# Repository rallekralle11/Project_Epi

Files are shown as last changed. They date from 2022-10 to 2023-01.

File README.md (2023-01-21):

# Epi
# This thing is about to get launched on Crowd Supply!
Also take a look at the better 4-layered version: https://github.com/rallekralle11/Epi_4L

Named after the Epipactis genus or orchids. The flower of one appears on the board.

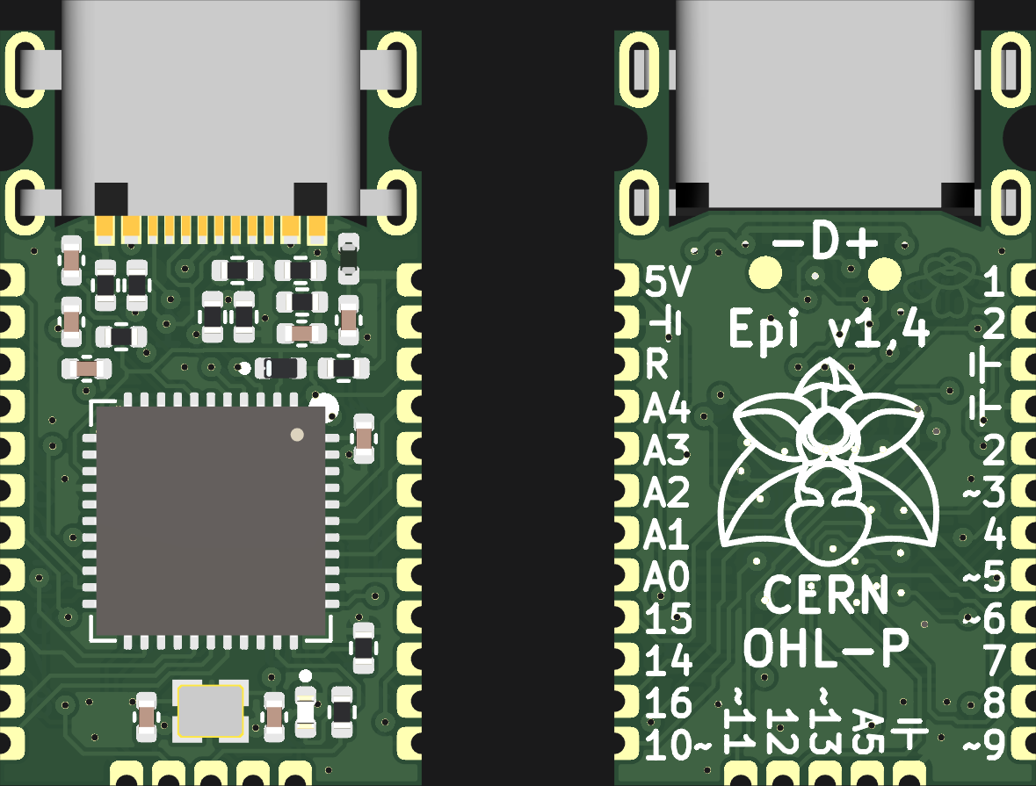
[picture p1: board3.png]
board


With such "amazing" features as:

Data line ESD protection taken from the official A. micro.

Crenellated pins.

No integrated voltage converter, only runs at 4,5-5,5v(down to 2,7 if you make it with an 8mhz crystal, or use the internal oscillator).

USB-C connector sunk into the board, and slighly portruding from the end for panel mounting.

1,27mm pin spacing.

Extra pins broken out.

Way too many hours routing for my sanity, and i doubt it's optimal(i am a beginner).

Holes where M2 bolts can be used to hold it in place.

No rx/tx/power LEDs. Only one on pin 13 for testing.

Includes some custom footprints with 3D models.

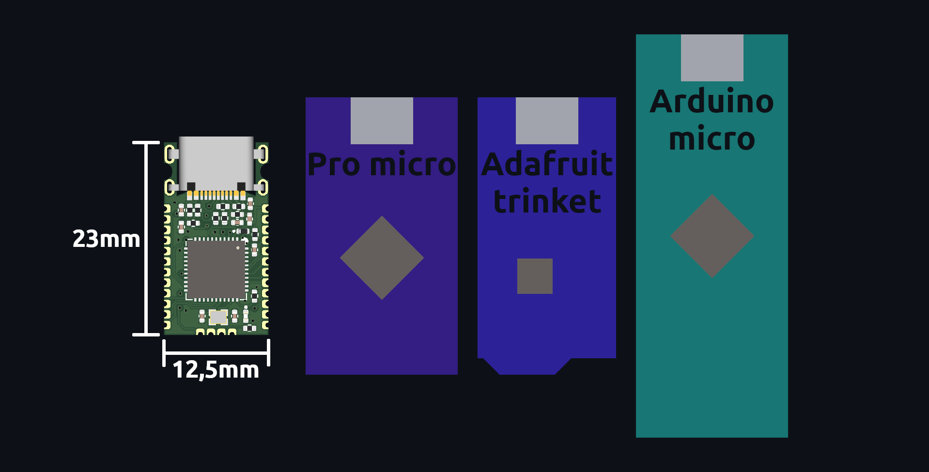
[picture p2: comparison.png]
comp

Size comparisons.

Licensed under CERN-OHL-P v2

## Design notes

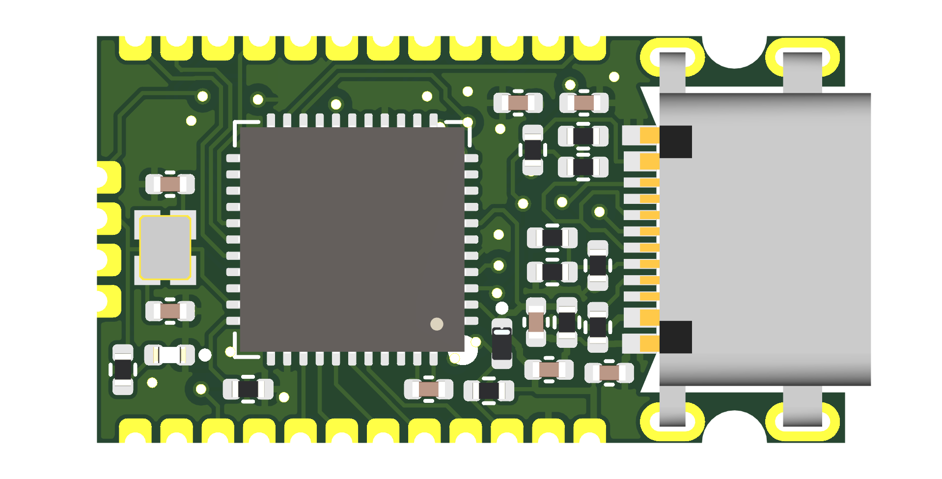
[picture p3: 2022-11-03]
diagram/pinout.png

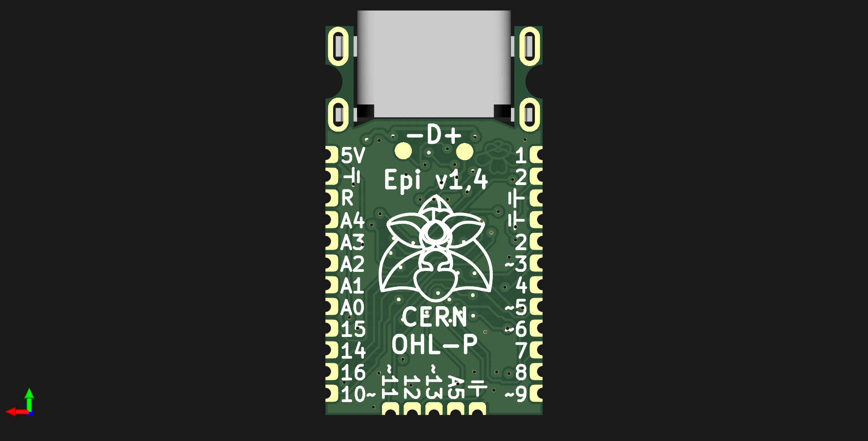
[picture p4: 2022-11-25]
B.png

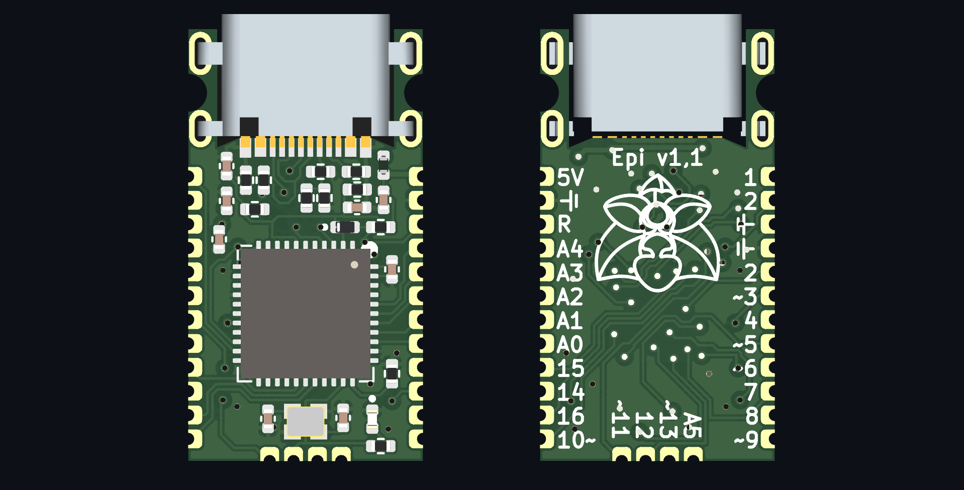
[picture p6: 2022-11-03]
gerbers/board2.png

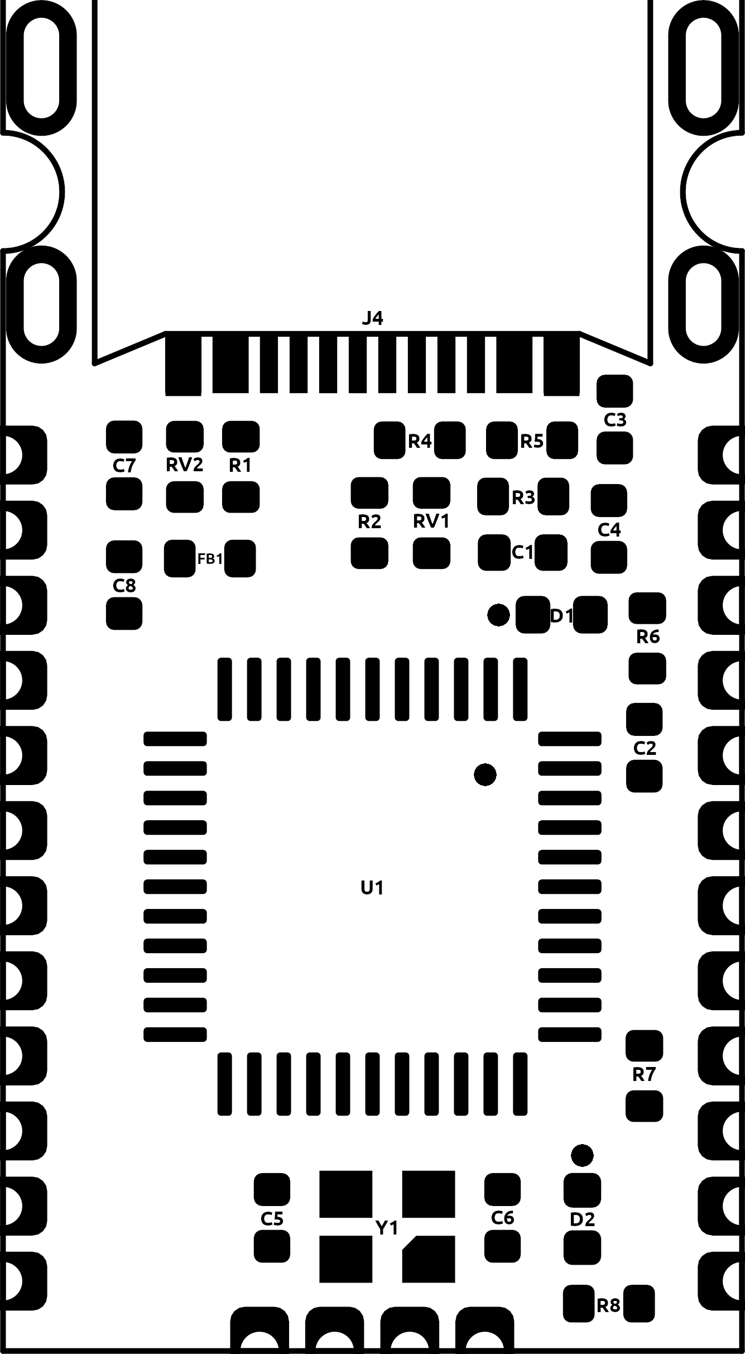
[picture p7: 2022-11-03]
diagram/layout.png

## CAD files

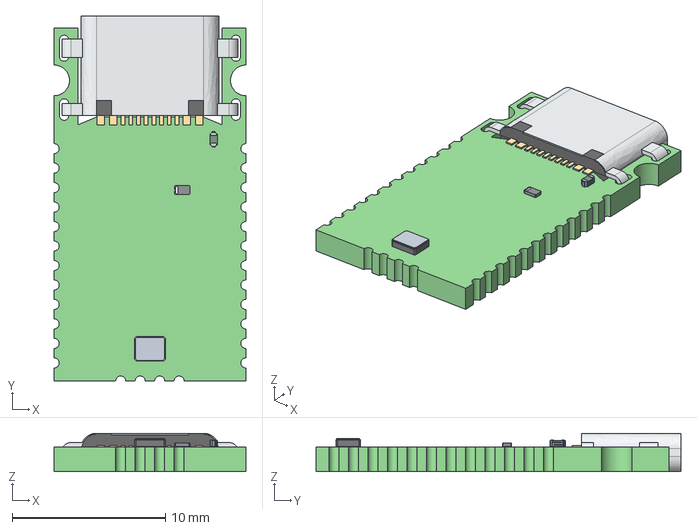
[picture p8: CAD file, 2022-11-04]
epi.step
12.5 x 23.8 x 2.50 mm
epi PCB

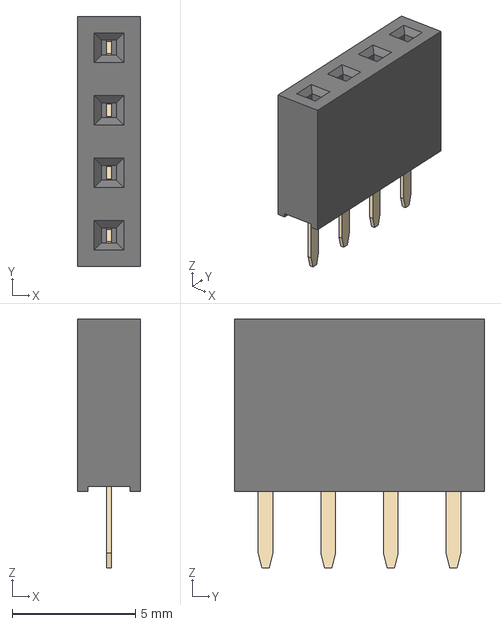
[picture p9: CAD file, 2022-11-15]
extra/PinSocket_1x04_P2.54mm_Vertical.step
2.54 x 10.2 x 10.1 mm

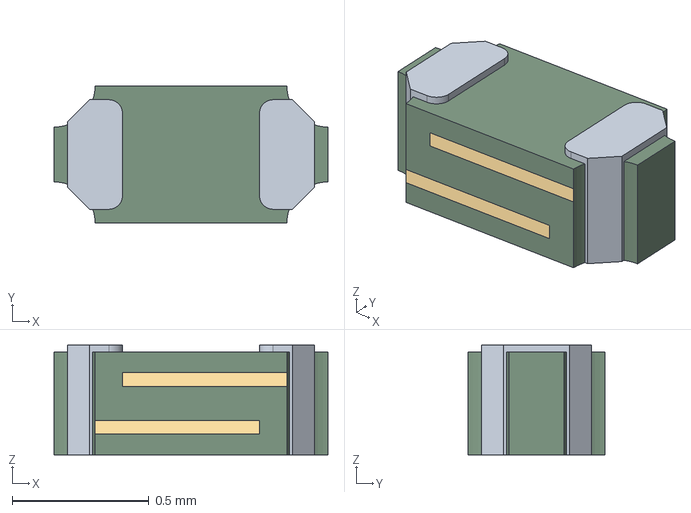
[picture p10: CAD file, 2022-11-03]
extra/1005_polyfuse.stp
1.00 x 0.5 x 0.4 mm

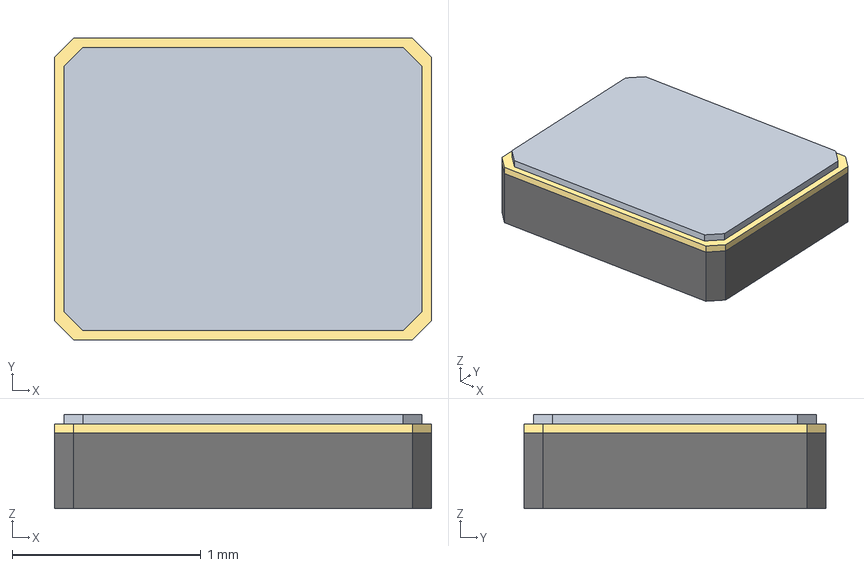
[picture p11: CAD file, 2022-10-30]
extra/crystal.stp
2.00 x 1.60 x 0.5 mm

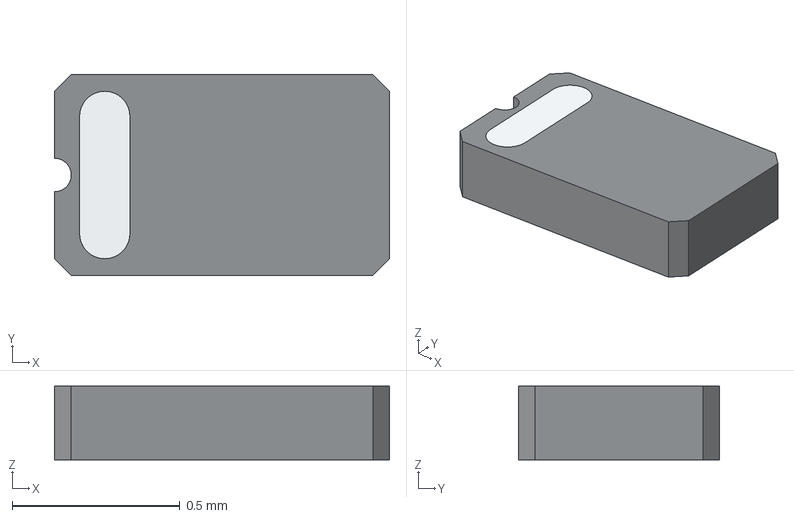
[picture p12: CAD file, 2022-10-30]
extra/diode.stp
1.00 x 0.6 x 0.22 mm

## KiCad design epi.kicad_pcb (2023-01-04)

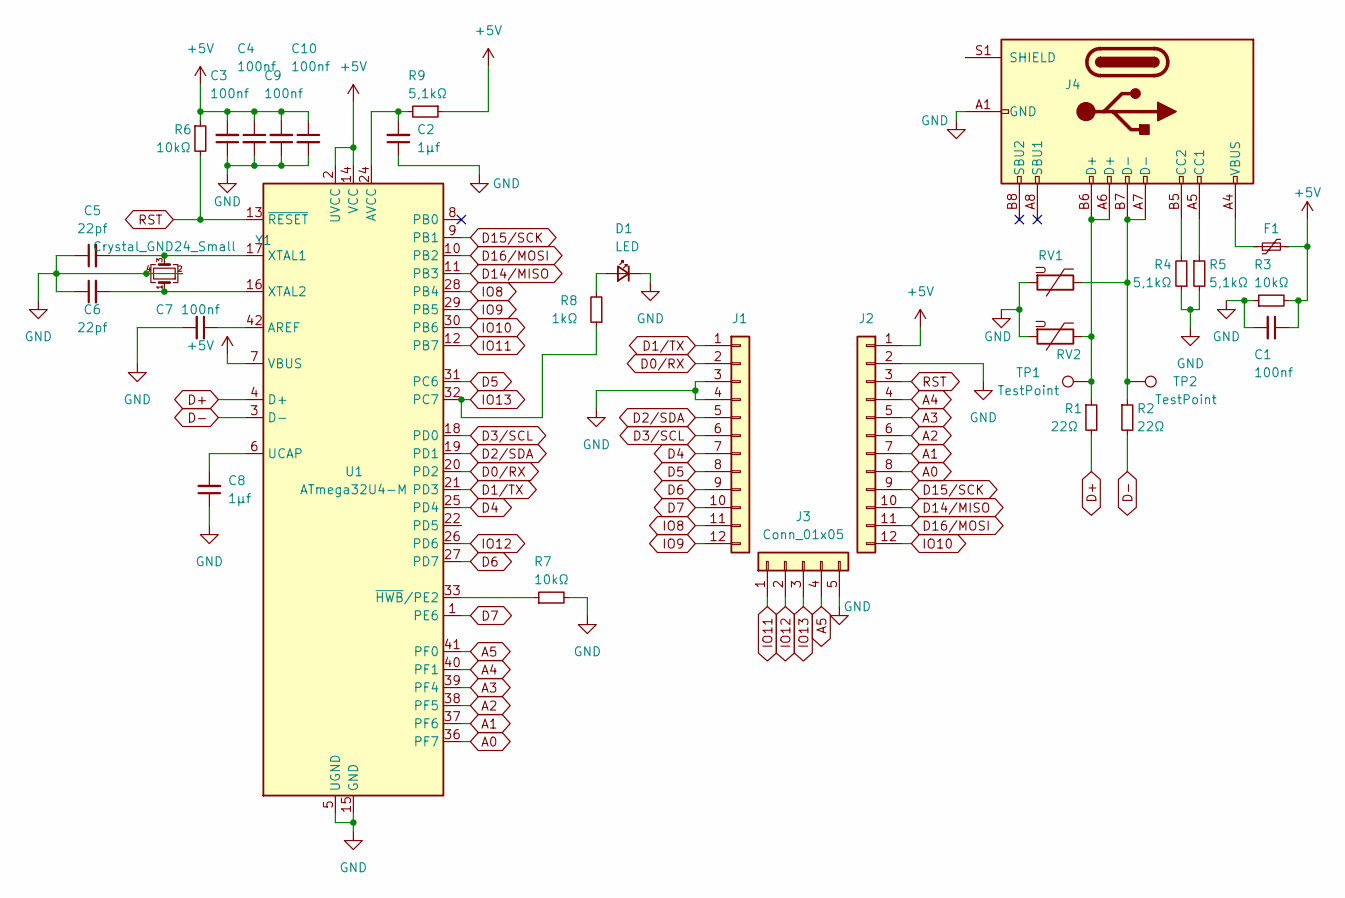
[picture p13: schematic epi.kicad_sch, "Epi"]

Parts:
C1, C3, C4, C7, C9, C10: 100nf; C_0402_1005Metric
C2, C8: 1µf; C_0402_1005Metric
C5, C6: 22pf; C_0402_1005Metric
D1: LED; LED_0402_1005Metric
F1: Polyfuse 500mA HC; Fuse_0402_1005Metric
J1, J2: Connector 1x12; PinHeader_1x12_P1.27mm_Vertical
J3: Conn_01x05; PinHeader_1x05_P1.27mm_Vertical
J4: USB-C 2.0 mid-mount female connector; USB-C MC-314C-4P16
R1, R2: 22Ω; R_0402_1005Metric
R3, R6, R7: 10kΩ; R_0402_1005Metric
R4, R5, R9: 5,1kΩ; R_0402_1005Metric
R8: 1kΩ; R_0402_1005Metric
RV1, RV2: ESD protection varistor; R_0402_1005Metric
TP1, TP2: TestPoint; TestPoint_Pad_D1.0mm
U1: ATmega32U4-M; QFN-44-1EP_7x7mm_P0.5mm_EP5.2x5.2mm
Y1: Crystal_GND24_Small; Crystal_SMD_2016-4Pin_2.0x1.6mm

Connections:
+5V: C1.1, C3.2, C4.1, C9.2, C10.1, F1.2, J2.1, R3.2, R6.1, R9.1, U1.2 (UVCC), U1.7 (VBUS), U1.14 (VCC), U1.34 (VCC)
A0: J2.8, U1.36 (PF7)
A1: J2.7, U1.37 (PF6)
A2: J2.6, U1.38 (PF5)
A3: J2.5, U1.39 (PF4)
A4: J2.4, U1.40 (PF1)
A5: J3.4, U1.41 (PF0)
D0/RX: J1.2, U1.20 (PD2)
D1/TX: J1.1, U1.21 (PD3)
D2/SDA: J1.5, U1.19 (PD1)
D3/SCL: J1.6, U1.18 (PD0)
D4: J1.7, U1.25 (PD4)
D5: J1.8, U1.31 (PC6)
D6: J1.9, U1.27 (PD7)
D7: J1.10, U1.1 (PE6)
D14/MISO: J2.10, U1.11 (PB3)
D15/SCK: J2.9, U1.9 (PB1)
D16/MOSI: J2.11, U1.10 (PB2)
D+: R1.2, U1.4 (D+)
D-: R2.2, U1.3 (D-)
GND: C1.2, C2.1, C3.1, C4.2, C5.1, C6.1, C7.2, C8.1, C9.1, C10.2, D1.1 (K), J1.3, J1.4, J2.2, J3.5, J4.A1 (GND), J4.A12 (GND), J4.B1 (GND), J4.B12 (GND), R3.1, R4.1, R5.2, R7.2, RV1.2, RV2.2, U1.5 (UGND), U1.15 (GND), U1.23 (GND), U1.35 (GND), U1.43 (GND), U1.45 (GND), Y1.2, Y1.4
IO8: J1.11, U1.28 (PB4)
IO9: J1.12, U1.29 (PB5)
IO10: J2.12, U1.30 (PB6)
IO11: J3.1, U1.12 (PB7)
IO12: J3.2, U1.26 (PD6)
IO13: J3.3, R8.1, U1.32 (PC7)
unnamed: C2.2, R9.2, U1.24 (AVCC), U1.44 (AVCC)
unnamed: C5.2, U1.17 (XTAL1), Y1.3
unnamed: C6.2, U1.16 (XTAL2), Y1.1
unnamed: C7.1, U1.42 (AREF)
unnamed: C8.2, U1.6 (UCAP)
unnamed: D1.2 (A), R8.2
unnamed: F1.1, J4.A4 (VBUS), J4.A9 (VBUS), J4.B4 (VBUS), J4.B9 (VBUS)
unnamed: J4.A5 (CC1), R5.1
unnamed: J4.A6 (D+), J4.B6 (D+), R1.1, RV2.1, TP1.1
unnamed: J4.A7 (D-), J4.B7 (D-), R2.1, RV1.1, TP2.1
unnamed: J4.B5 (CC2), R4.2
unnamed: R7.1, U1.33 (~HWB/PE2)
RST: J2.3, R6.2, U1.13 (~RESET)

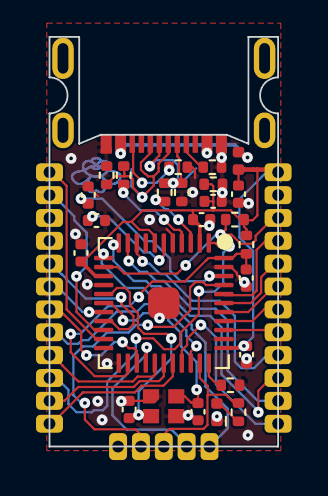
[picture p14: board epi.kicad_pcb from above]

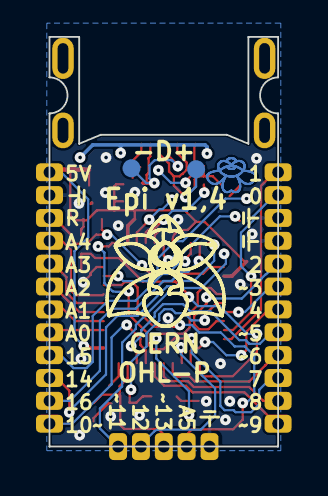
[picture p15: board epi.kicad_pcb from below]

Board: 2 copper layers, 12.7 x 22.8 mm, 31 parts (2 on the bottom side), 40 nets.

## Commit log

2022-10-29 adding everything
    [pro_tiny.dsn, pro_tiny.kicad_pcb, pro_tiny.kicad_sch]
2022-10-29 board updates and readme
    [pro_tiny.kicad_pcb]
2022-10-29 bit of everything
    [pro_tiny.kicad_pcb]
2022-10-29 finished routing main pins
    [pro_tiny.kicad_pcb, pro_tiny.kicad_sch]
2022-10-30 finished routing and more
    [USB-C.stp, crystal.stp, pro_tiny.kicad_pcb]
2022-10-30 added better picture
    [pro_tiny.kicad_pcb]
2022-10-30 changed 3D models and updated picture
    [USB-C.stp, crystal.stp, diode.stp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]
2022-10-30 bit of everything and name change
    [crystal.stp, diode.stp, epi.dsn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]
2022-10-30 small trace fix
    [epi.kicad_pcb]
2022-10-30 added comparison picture
    [epi.kicad_pcb]
2022-10-30 mixed changes
    [epi-B_Cu.gbr, epi-B_Mask.gbr, epi-B_Paste.gbr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]
2022-10-31 slight redesign
    [epi-B_Cu.gbr, epi-B_Mask.gbr, epi-B_Paste.gbr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]
2022-10-31 pictures and readme
    [epi_BOM.csv]
2022-10-31 comparison pic ++
    [epi.kicad_pcb]
2022-10-31 mostly readme
    [epi.kicad_pcb]
2022-11-01 experimental production files update++
    [epi-B_Cu.gbr, epi-B_Mask.gbr, epi-B_Paste.gbr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]
2022-11-03 redesign, added fuse
    [1005_polyfuse.stp, duemilanove.kicad_pcb, duemilanove.kicad_sch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]
2022-11-03 updated gerbers and removed misplaced folder
    [duemilanove.kicad_pcb, duemilanove.kicad_sch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]
2022-11-04 fixed small USB port inaccuracy
    [epi.kicad_pcb, epi.kicad_sch, epi.step]
2022-11-04 updated BOM
    [epi_BOM.csv]
2022-11-04 more descriptive part names and better BOM
    [epi.kicad_pcb, epi.kicad_sch, epi_BOM.csv]
2022-11-05 increased trace spacing and a few other changes
    [epi-B_Cu.gbr, epi-B_Mask.gbr, epi-B_Paste.gbr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]
2022-11-08 bit of this and bit of that
    [epi.kicad_pcb, epi.kicad_sch]
2022-11-08 updaated gerbers
    [epi-B_Cu.gbr, epi-B_Mask.gbr, epi-B_Paste.gbr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]
2022-11-15 fixed some dumb missed connection
    [PinSocket_1x04_P2.54mm_Vertical.step, epi.csv, epi.kicad_pcb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]
2022-11-15 removed unused files
    [epi.csv, pro_tiny.kicad_pcb, pro_tiny.kicad_sch]
2022-11-25 updated pictures
    [epi.kicad_pcb]
2022-12-08 fixed a wrong pin number
    [epi.kicad_pcb]
2023-01-04 messed up and reuploaded it all
    [epi.dsn, epi.kicad_pcb, epi.kicad_sch]

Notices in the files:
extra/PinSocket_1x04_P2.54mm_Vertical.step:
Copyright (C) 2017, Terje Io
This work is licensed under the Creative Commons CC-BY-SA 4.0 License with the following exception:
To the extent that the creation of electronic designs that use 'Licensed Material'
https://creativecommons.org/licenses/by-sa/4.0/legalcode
